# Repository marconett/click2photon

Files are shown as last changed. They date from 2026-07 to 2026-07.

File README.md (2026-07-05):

# click2photon

End-to-end display latency measurement: the time from a mouse click to a visible
change on screen, measured with a photodiode strapped to the monitor.

**How it works:**

- An RP2040 sends a USB HID mouse click
- The color switcher app toggles the screen black/white
- The photodiode picks up the change
- The RP2040 streams ADC samples over serial
- The host logs them to CSV
- `analyze.py` computes the latency

## Components

| Component | Path | Description |
|---|---|---|
| Hardware | `hardware/` | KiCad PCB, breadboard/perfboard layout, and 3D-printable enclosure for the sensor (BPW34 photodiode + TLC271IP transimpedance amplifier). |
| Firmware | `arduino/` | Runs on an Adafruit QT Py RP2040. Fires the mouse click, samples the photodiode (14-bit ADC, 12,000 samples per run), sends results as CSV lines over serial. Flash with `./flash_rp2040.sh`. |
| Host software | `main.py` | Interactive serial terminal. Starts/stops test runs, configures click count and interval, logs device data to `output/*.csv`. |
| Analyzer | `analyze.py` | Computes latency from a session CSV: delta-from-baseline threshold detection, reports per-click latency plus mean/sd/median/min/max. |
| Color switcher | `color-switcher-vulkan/` | C++ Vulkan app that toggles the screen black/white on click, built for minimal rendering latency. Build with `./build_vulkan.sh`, run with `./run_vulkan.sh`. |

## Images

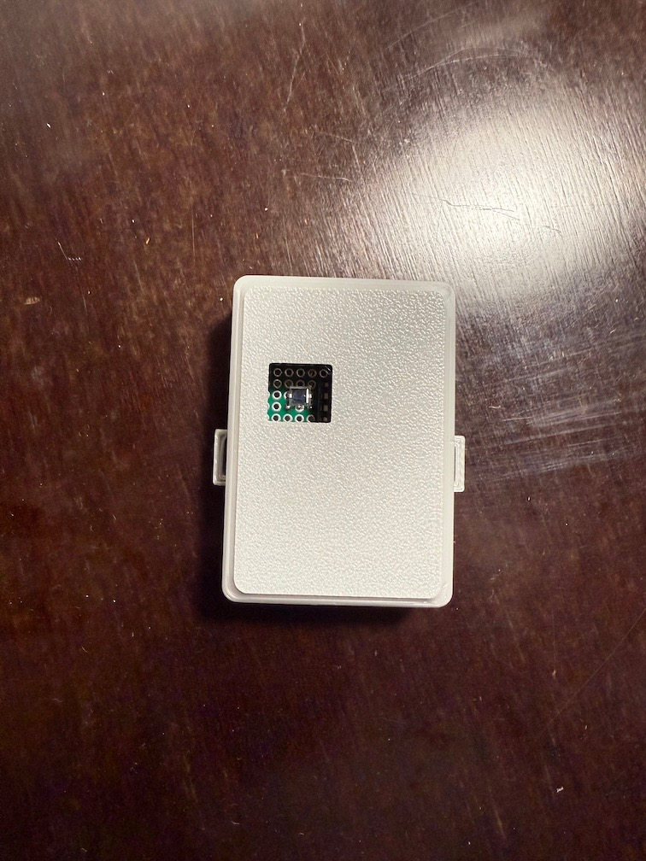
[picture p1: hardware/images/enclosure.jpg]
Enclosure
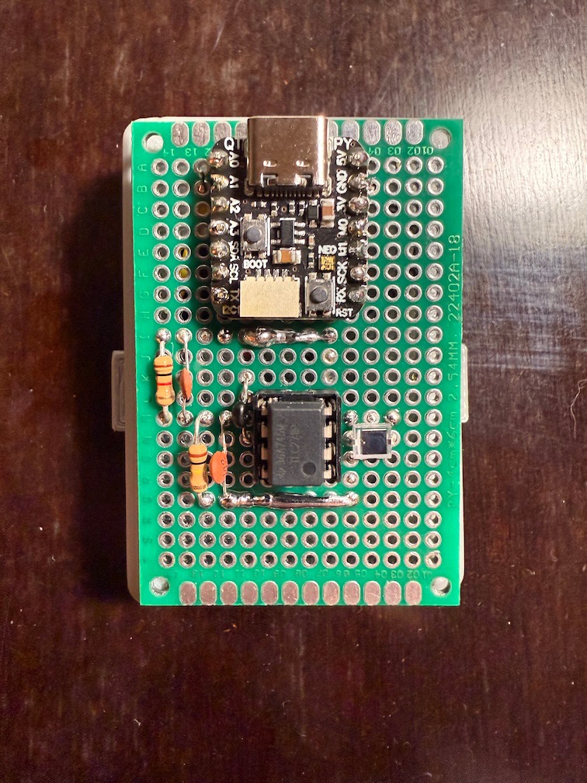
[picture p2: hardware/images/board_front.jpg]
Board
 

## Host software CLI (`main.py`)

Connects to the device on `/dev/cu.usbmodem101` at 115200 baud and provides an
interactive prompt:

| Command | Description |
|---|---|
| `start` | Start a test session (3s countdown). Logs to `output/<timestamp>_session.csv`. |
| `stop` | Stop the test and close the session CSV. |
| `debug`, `d` | Enable debug mode — device streams raw ADC readings and voltage. |
| `interval <float>`, `i <float>` | Set the time between clicks in seconds (default 0.5). |
| `clicks <int>`, `c <int>` | Set the number of clicks per session (default 10). |
| `connect` / `disconnect` | Open / close the serial connection. |
| `help` | Show the command list. |
| `exit`, `quit` | Disconnect and quit. |

## Usage

```sh
uv sync                     # set up Python environment
./run_vulkan.sh             # start the color switcher on the monitor under test
uv run main.py              # connect to the device, then type: start
uv run analyze.py output/<session>.csv
```

## Similar tools

Multiple similar (and likely better) tools / devices exist:

- [m2p-latency](https://github.com/davidramiro/m2p-latency)
- [Open-Source-LDAT](https://github.com/S4N-T0S/Open-Source-LDAT)
- [OSLTT](https://github.com/OSRTT/OSLTT)

As well as amazing articles detailing the process and results:

- By @farnoy: [Linux latency measurements and compositor tuning](https://farnoy.dev/posts/linux-latency)
- By @davidramiro: [Building an Input Latency Meter (Because ‘Wayland Feels Off’ Isn’t a Metric)](https://davidjusto.com/articles/m2p-latency/)

For fun, I let Claude Fable 5 compare the 4 projects: [COMPARISON.md](./COMPARISON.md).

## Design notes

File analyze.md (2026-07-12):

# analyze.py output explained

Each value describes the click-to-photon latencies of one file or one pooled folder (all clicks from all its CSV files together).

- **measurements** — number of clicks with a detected screen change. *skipped* = clicks where no change crossed the threshold (bad sample, missed click); they are excluded from all stats.

- **mean ± … (95% CI)** — average latency. The ± is the uncertainty of that average: rerunning the same test would land the mean inside this range 95% of the time. Two cases whose ranges don't overlap are genuinely different. For folders, the margin is widened if the individual sessions disagree with each other.

- **median** — the middle click: half were faster, half slower. Like the mean but immune to a few extreme values.

- **p5** — the fast tail: 5% of clicks were faster than this. Approximates the best-case pipeline latency (click landed at the luckiest moment of the refresh cycle). A robust version of *min*.

- **p95** — the slow tail: 5% of clicks were slower than this. The "feels laggy" number — worst cases players actually notice. Where frame-pacing features should show their effect.

- **spread (p95 − p5)** — consistency: how wide the typical latency range is. Smaller = more predictable feel. More meaningful than sd, which is inflated the same way everywhere.

- **min / max** — single fastest and slowest click. Sanity checks only; each is one sample, so don't base conclusions on them.

- **histogram** — latency distribution in 0.5 ms bins; each row shows a bin's count as a bar. Shows the shape a single number can't: whether the whole block shifts between cases, whether a case has a longer tail, or whether clicks clump at multiples of the 2 ms frame period.

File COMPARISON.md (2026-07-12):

# Comparing four open-source display latency testers

A comparison of this project (**click2photon**) against three tools that fulfil the same purpose:

- [davidramiro/m2p-latency](https://github.com/davidramiro/m2p-latency)
- [S4N-T0S/Open-Source-LDAT](https://github.com/S4N-T0S/Open-Source-LDAT)
- [OSRTT/OSLTT](https://github.com/OSRTT/OSLTT)

**Quick orientation:** all four measure "input event → visible photon" with a light sensor on the screen, but they split into two design philosophies. **m2p-latency** and **Open-Source-LDAT** are *standalone devices*: they time a live threshold crossing on the microcontroller and show summary stats on an OLED — no host software, no raw data. **OSLTT** and **click2photon** are *capture-and-analyze systems*: the firmware records a full ADC waveform per shot and streams it to the PC, where detection happens offline. This project is visibly a hybrid of the other three — it shares OSLTT's capture architecture almost exactly (14-bit ADC, 12,000 samples, 115200 baud, near-identical CSV header), m2p's delta-from-baseline detection algorithm (credited in `analyze.py`), and OSLTT's dedicated black/white test app idea (the Vulkan color-switcher vs. their DirectX window).

## 1. Measurement approach

| | m2p-latency | Open-Source-LDAT | OSLTT | click2photon |
|---|---|---|---|---|
| Input event | Mouse **move** (±127 px) via ATmega32U4 HID | Real-mouse switch injection (transistor) **or** Teensy as 8 kHz HID mouse | HID keyboard space / mouse click / mouse move | `Mouse.press()` via RP2040 HID |
| Detection | Live busy-poll, \|delta from 1-sample baseline\| > 20 (10-bit) | Live busy-poll, fixed threshold w/ hysteresis (>15 / <10 on 8-bit) | Waveform capture → host-side smoothing + slope-confirmation lookaheads | Waveform capture → host-side \|delta from 200-sample baseline\| > 100 (14-bit) |
| Timing location | On MCU (`micros()`) | On MCU (`elapsedMicros`) | MCU captures, host detects | MCU captures, host detects |
| Raw data kept | No | No (only per-run ms to SD, optionally) | Yes (full 12k-sample CSV) | Yes (full 12k-sample CSV) |
| Pre-click baseline | 1 sample | None (fixed thresholds) | None — capture starts *at* the click; baseline inferred from first 50 samples | 2,000 samples (~48 ms) before the click |

The most important architectural differences:

- **What the click includes.** Open-Source-LDAT's "Automatic" mode is unique: it electrically actuates a *real mouse's* switch, so the measurement includes the mouse's own hardware/firmware/debounce latency — true click-to-photon, and anticheat-invisible (the device can run PC-disconnected on a power bank). Everyone else emulates a HID device, which measures system+display latency but excludes real-mouse internals.
- **Pre-click history.** This project is the only one that samples *before* the click (2,000 samples), giving a proper averaged baseline and letting you see ADC drift. OSLTT starts capturing after the HID call returns and adds the call duration back arithmetically; m2p uses one un-averaged sample as baseline; LDAT uses no baseline at all, just fixed thresholds that must be hand-tuned per monitor.
- **Detection sophistication.** OSLTT has the most elaborate detector (10-sample moving average, pulse/rising/falling branches, multi-point lookahead confirmation at +50/+100/+150 samples, adaptive false-trigger handling) — robust but complex. This project's and m2p's simple delta-threshold is easier to reason about but sensitive to threshold choice; LDAT's fixed absolute threshold is the crudest but runs at the highest speed.

## 2. Measurement accuracy

| | m2p-latency | Open-Source-LDAT | OSLTT | click2photon |
|---|---|---|---|---|
| ADC resolution | 10-bit (overclocked, noisy) | 8-bit (deliberately, for speed) | 14-bit | 14-bit |
| Effective sample interval | ~13–20 µs | ~1–3 µs (600 MHz busy-poll) | ~15.27 µs | ~24 µs (20 µs settling + read) |
| Timer resolution | 4 µs | 1 µs | 1 µs | 1 µs |
| Refresh-phase decorrelation | 574 ms delay (non-divisor of refresh) | Entropy-seeded ±10 ms random jitter | Configurable 0.5–8 s delay, no jitter | Fixed interval, no jitter |
| Stats | Mean + sample SD over 20 runs | Running mean/min/max, B→W and W→B tracked separately | Mean/min/max + **median-based outlier rejection** (>3× or <⅓ median dropped) | Mean, sample SD, median, min/max |
| Calibration aids | Live sensor bar for positioning; fixed 40 µs internal-latency subtraction | Boot-time sensor stability self-check; debug live-ADC mode; thresholds need reflash to change | Per-run sample-period self-calibration; frame-time subtraction | Documented 20 µs settling fix; `-t` threshold override |

Accuracy verdicts per tool:

- **Open-Source-LDAT** has the best *temporal* precision (sub-3 µs detection granularity, 1 µs timer, genuine 8 kHz USB polling via a build-time Teensy core patch that cuts HID poll quantization to 0–125 µs) but the worst *amplitude* precision (8-bit ADC, fixed thresholds calibrated for OLED monitors — LCD users must retune). Its README is also the most honest about the latency pipeline: min/max spread of several ms is expected physics (frame timing + scanout), not instrument error.
- **OSLTT** is the only one that decomposes the result: it measures the test window's frame time (~1000 FPS DirectX app, QueryPerformanceCounter) and reports `onDisplayLatency = total − frameTime`, plus a "pretest" mode that subtracts system baseline to isolate game-engine latency. It's also the only one with outlier rejection. Weaknesses admitted in its own code: frame time is logged one frame late, and the moving average shifts the detected transition by 10 samples.
- **m2p-latency** is the roughest: single-sample baseline, ADC clocked 8× beyond its datasheet accuracy limit, 4 µs timer, USB poll jitter of the Pro Micro uncharacterized. The README itself calls it "a rough estimate." Its one clever accuracy feature — the 574 ms inter-cycle delay chosen not to divide the refresh rate — reappears in stronger form as LDAT's randomized jitter.
- **click2photon** has the best amplitude fidelity of the capture-based pair: 14-bit ADC *plus* the 20 µs settling delay (OSLTT reads flat-out with no settling, which compresses dynamic range), and the only real pre-click baseline. Trade-offs: the ~24 µs sample interval quantizes detection slightly coarser than OSLTT's ~15 µs, latency is reconstructed as `index × (timeTaken/sampleCount)` (assumes uniform sample spacing), and there is no refresh-phase jitter/decorrelation between shots — worth stealing from LDAT.

## 3. Hardware choice

| | m2p-latency | Open-Source-LDAT | OSLTT | click2photon |
|---|---|---|---|---|
| MCU | Arduino Pro Micro (ATmega32U4, 16 MHz, ~$8) | Teensy 4.1 (Cortex-M7 @ 600 MHz, ~$35) | Seeeduino XIAO / custom SAMD21 PCB | Adafruit QT Py RP2040 (~$10) |
| Sensor | TEMT6000 phototransistor breakout | TEMT6000 phototransistor breakout | VBPW34SR photodiode + TSV7721 transimpedance amp (1 MΩ) | BPW34 photodiode + TLC271 transimpedance amp |
| Extra hardware | SSD1306 OLED, MX button | SSD1306 OLED, button, BC547 mouse-injection circuit, microSD logging | Mic input + amp, 2-pin/3-pin trigger inputs, button, LED; sold as assembled kit | KiCad PCB, breadboard layout, 3D-printed enclosure |
| Approx. cost | ~$15–20 | ~$45–55 + donor mouse | Commercial kit (osrtt.com); ~$10–20 BOM class | ~$15–25 |

Two meaningful splits here. First, **phototransistor vs. photodiode+amp**: the TEMT6000 (m2p, LDAT) is a $2 plug-and-play breakout — simple but slower and less linear. This project and OSLTT independently chose the harder path of a PIN photodiode with a transimpedance amplifier, which gives faster, more linear response at the cost of analog design work (BPW34+TLC271 vs. their VBPW34SR+TSV7721 are essentially the same circuit with different parts). Second, **MCU horsepower**: LDAT's Teensy 4.1 is wildly overpowered on purpose — the 600 MHz core is what buys the ~1 µs detection loop. The other three all use ~$5–10 hobby boards where USB HID support was the actual selection criterion. OSLTT is the only one that graduated to a custom manufactured PCB sold as a product.

## 4. Ease of use

- **m2p-latency** is the easiest to *operate*: plug in USB, point at testufo.com/flicker or a game, press the button, read mean±σ off the OLED 20 clicks later. No software, OS-agnostic. But it's the least flexible — changing anything (cycle count, threshold) means recompiling, and there's no data export at all.
- **Open-Source-LDAT** is the hardest to *build* (soldering, sacrificing a mouse for Automatic mode, per-monitor threshold tuning that requires editing `config.h` and reflashing via PlatformIO) but pleasant to run: one-button on-device menu, run limits of 10/100/300/500/unlimited, live stats, optional CSV to microSD. It needs a third-party "latency marker" on screen (NVIDIA Reflex flash indicator, RTSS FCAT bar, or Aperture Grille) — those tools are Windows-centric even though the device itself is OS-agnostic. Documentation is excellent.
- **OSLTT** is the most polished end-user experience by far — it's a commercial product: Windows installer, GUI that auto-installs drivers and auto-flashes firmware updates, built-in ~1000 FPS DirectX test window, up to 990 automated shots, result charts, CSV export of both raw and processed data, and extra modes nobody else has (peripheral click latency via microphone/electrical tap, audio latency, controller latency). The cost: Windows-only, closed ecosystem feel, and a large codebase its own author calls imperfect.
- **click2photon** is the most developer/researcher-oriented: CLI workflow (`uv run main.py`, `uv run analyze.py`), full raw waveforms in versioned CSVs, a purpose-built low-latency Vulkan test app, and macOS support — which none of the other three targets (OSLTT is Windows-only; the standalone devices are OS-agnostic but their recommended marker apps are Windows tools). The trade-off is that it's a three-part manual workflow (start Vulkan app, run terminal UI, run analyzer) with no GUI and no on-device operation.

## Takeaways

Ideas worth borrowing: **LDAT's randomized inter-shot jitter** (decorrelating from display refresh) is a cheap accuracy win the fixed-interval firmware currently lacks, and **LDAT's real-mouse switch injection** is the only approach here that captures true click-to-photon including mouse hardware latency. Conversely, the combination of pre-click baseline sampling, 14-bit ADC with settling delay, and full waveform retention gives this project better post-hoc analyzability than any of the three references — none of them can re-analyze old runs with a different detection algorithm, and this one can.

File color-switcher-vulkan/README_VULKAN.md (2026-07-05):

# Vulkan Color Switcher

### Installation on macOS

```bash
brew install vulkan-headers vulkan-loader molten-vk glfw cmake
```

## Building

```bash
cd color-switcher-vulkan/build
cmake ..
cmake --build .
```

## Running

```bash
./color-switcher-vulkan/build/bin/color-switcher-vulkan
```

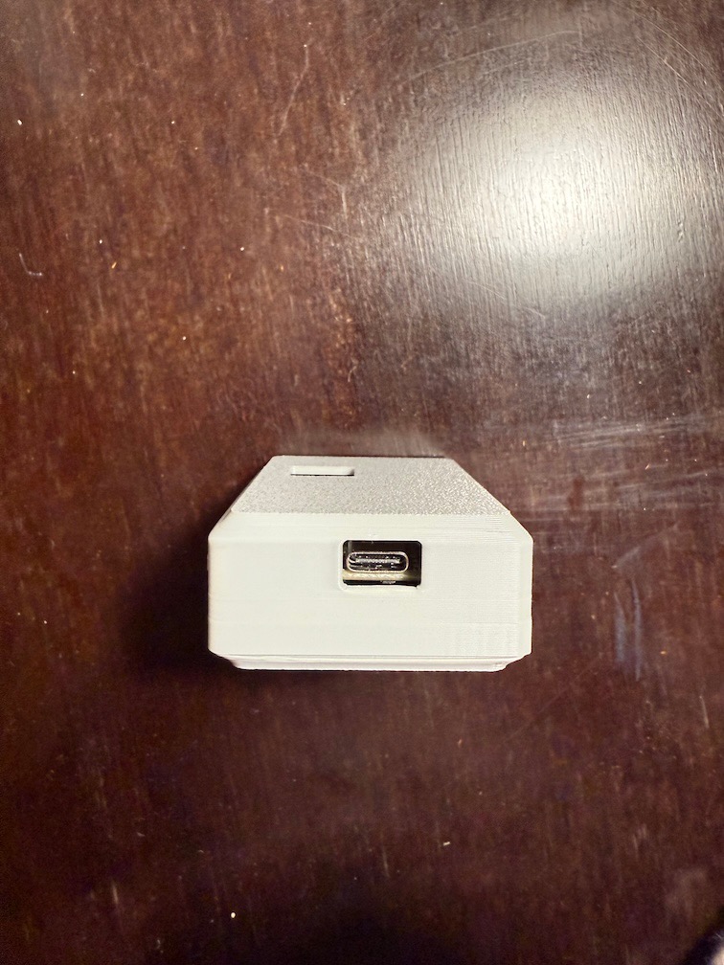
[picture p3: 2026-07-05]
hardware/images/enclosure_side.jpg

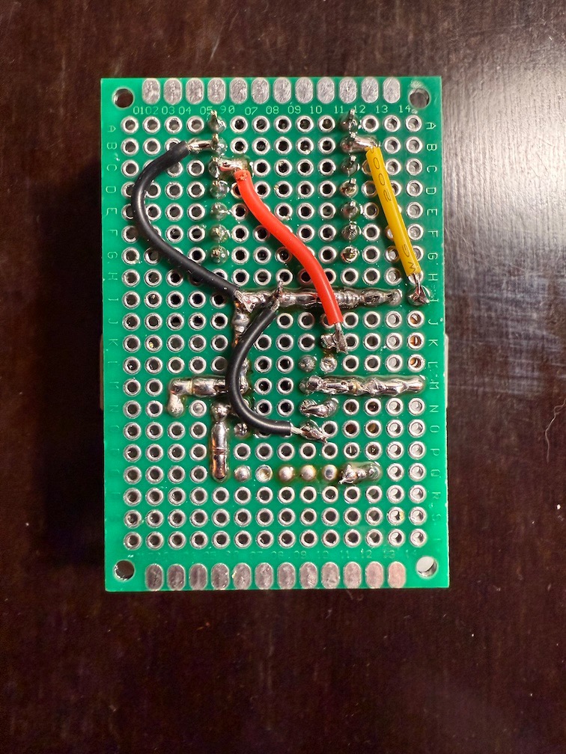
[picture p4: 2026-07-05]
hardware/images/board_back.jpg

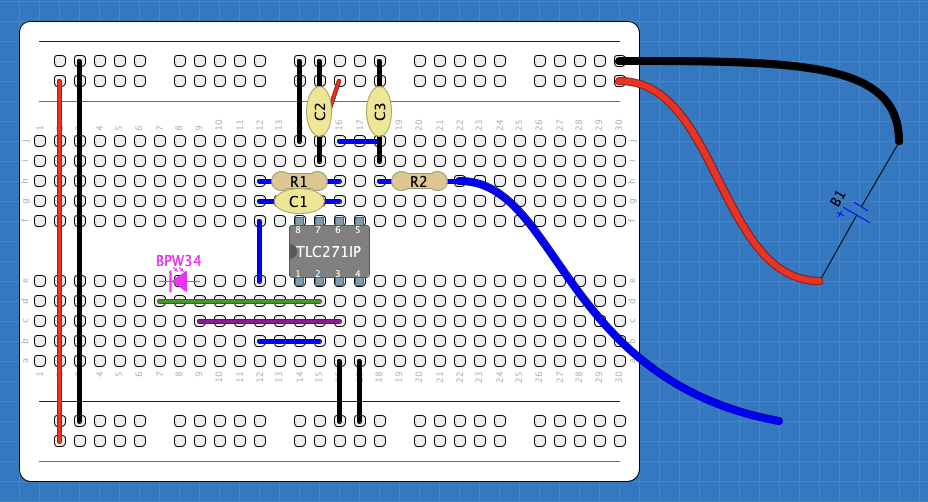
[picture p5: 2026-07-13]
hardware/breadboard.png

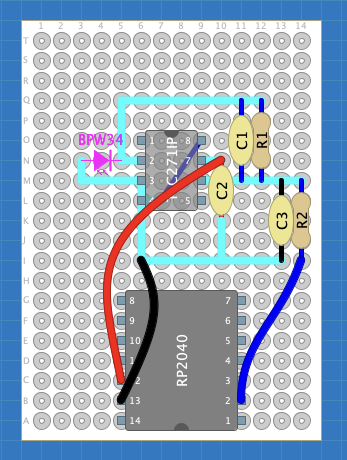
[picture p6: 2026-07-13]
hardware/perfboard.png

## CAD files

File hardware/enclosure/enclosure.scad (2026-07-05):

include <./YAPPgenerator_v3.scad>

pcbLength = 40;
pcbWidth = 60;
pcbThickness = 1.6;

// paddingFront = 1.5;
// paddingBack = 1.5;
// paddingRight = 2.5;
// paddingLeft = 2.5;

// ridgeHeight = 6;
lidWallHeight  = 13;
baseWallHeight = 6;
wallThickness = 2;

standoffHeight = 6;
standoffDiameter = 4.5;
standoffPinDiameter = 1.94;
standoffHoleSlack = 0.6;

// * Print settings *
// printLidShell = false;
// printBaseShell = false;

// * Debug settings *
// showPCB = true;
// hideLidWalls = true;
// showSideBySide = false;
// onLidGap = 6;

// snapJoins = [
//     [6, 6, yappLeft, yappRight],
//     [pcbLength+paddingRight+paddingLeft-6, 6, yappLeft, yappRight]
// ];

pcbStands = [
    [2.5, 2.5, standoffHeight, yappDefault, standoffDiameter, standoffPinDiameter, standoffHoleSlack, 0, yappBoth, yappPin, yappAllCorners, yappCoordPCB]
];

// hole for usb-c connector
cutoutsLeft = [
    [
      ((pcbLength-13)/2) + 2.54, // from Back
      3, // from Left
      11, // width
      7, // length
      1, // radius
      yappRoundedRect, // shape
      0, // depth
      0, // angle
      // yappCenter,
      yappCoordPCB,
    ]
];

// hole for the photodiode
cutoutsLid = [
    [5, 33, 13, 12, 6, yappRectangle]
];

// module hookLidInside()
// {
  // translate([20, 34, -5])
  //   cube([2, 12, 12]);

  // translate([20+14, 34, -5])
  //   cube([2, 12, 12]);

  // translate([20, 34-2, -5])
  //   cube([16, 2, 12]);

  // translate([20, 34+12, -5])
  //   cube([16, 2, 12]);
// }

// guides for the elastic band
module hookLidOutside()
{
  // back
  // base x value: -4
  translate([-6, 20, -12.5])
    cube([2, 10, 3]);

  translate([-6, 20, -12.5])
    cube([4, 2, 3]);

  translate([-6, 30, -12.5])
    cube([4, 2, 3]);

  // front
  // base x value: 44
  translate([46, 20, -12.5])
    cube([2, 10, 3]);

  translate([44, 20, -12.5])
    cube([4, 2, 3]);

  translate([44, 30, -12.5])
    cube([4, 2, 3]);
}

YAPPgenerate();

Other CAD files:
hardware/enclosure/YAPPgenerator_v3.scad

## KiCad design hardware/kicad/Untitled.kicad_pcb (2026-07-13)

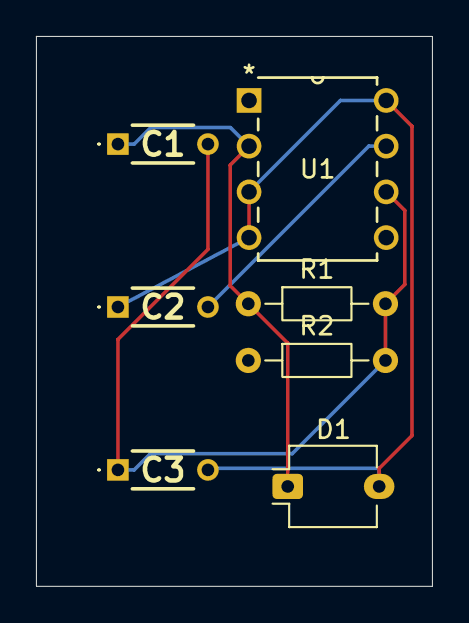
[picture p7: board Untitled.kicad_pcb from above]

Board: 2 copper layers, 22.0 x 30.5 mm, 7 parts (0 on the bottom side), 4 nets.

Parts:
C1: 1pF; K104K15X7RF53H5G
C2, C3: 100nF; K104K15X7RF53H5G
D1: BPW34; Osram_DIL2_4.3x4.65mm_P5.08mm
R1: 100kΩ; R_Axial_DIN0204_L3.6mm_D1.6mm_P7.62mm_Horizontal
R2: 1kΩ; R_Axial_DIN0204_L3.6mm_D1.6mm_P7.62mm_Horizontal
U1: TLC271IP

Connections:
+3.3V: C2.2, U1.7 (VDD)
GND: C2.1, C3.2, D1.2 (A), U1.3 (IN+), U1.4 (GND), U1.8 (BIASSELECT)
unnamed: C1.1, D1.1 (K), R1.1, U1.2 (IN-)
unnamed: C1.2, C3.1, R1.2, R2.2, U1.6 (OUT)

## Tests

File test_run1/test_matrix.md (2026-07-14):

# Test Matrix

Three dimensions, two values each → **8 test cases**.

**Dimensions**
- **Display server:** X11 / Wayland
- **`PROTON_DXVK_LOWLATENCY`:** ON / OFF
- **VRR:** ON / OFF

- Plus another 2 special test cases for XWayland
- Plus another 2 special test cases for low-latency

---

## Test Cases

| #  | Display | LOWLATENCY | VRR | Special case | Done |
|----|---|---|-----|---|---|
| 1  | X11 | ON | ON  | - | [x]  |
| 2  | X11 | ON | OFF | - | [x]  |
| 3  | X11 | OFF | ON  | - | [x]  |
| 4  | X11 | OFF | OFF | - | [x]  |
| 5  | Wayland | ON | ON  | - | [x]  |
| 6  | Wayland | ON | OFF | - | [x]  |
| 7  | Wayland | OFF | ON  | - | [x]  |
| 8  | Wayland | OFF | OFF | - | [x]  |
| 9  | Wayland | ON | OFF | XWayland | [x]  |
| 10 | Wayland | OFF | OFF | XWayland | [x]  |
| 11 | X11 | ON | OFF | Uncapped | [x]  |
| 12 | X11 | OFF | OFF | Uncapped | [x]  |

---

## Per-Case Notes

### Case 1 — X11 · LOWLATENCY ON · VRR ON
- stable 480 fps

```conf
# dxvk.conf
dxgi.maxFrameRate = 480
dxvk.lowLatencyOffset = 70
dxvk.framePace = "low-latency-vrr-500"
dxvk.lowLatencyAllowCpuFramesOverlap = False
```

### Case 2 — X11 · LOWLATENCY ON · VRR OFF
- stable 500 fps

```conf
# dxvk.conf
dxgi.maxFrameRate = 500
```

### Case 3 — X11 · LOWLATENCY OFF · VRR ON
- stable 497 fps

```conf
# dxvk.conf
dxgi.maxFrameRate = 497
```

### Case 4 — X11 · LOWLATENCY OFF · VRR OFF
- stable 500 fps

```conf
# dxvk.conf
dxgi.maxFrameRate = 500
```

### Case 5 — Wayland · LOWLATENCY ON · VRR ON
- stable 480 fps

```conf
# dxvk.conf
dxgi.maxFrameRate = 480
dxvk.lowLatencyOffset = 70
dxvk.framePace = "low-latency-vrr-500"
dxvk.lowLatencyAllowCpuFramesOverlap = False
```

### Case 6 — Wayland · LOWLATENCY ON · VRR OFF
- stable 500 fps

```conf
# dxvk.conf
dxgi.maxFrameRate = 500
```

### Case 7 — Wayland · LOWLATENCY OFF · VRR ON
- stable 497 fps

```conf
# dxvk.conf
dxgi.maxFrameRate = 497
```

### Case 8 — Wayland · LOWLATENCY OFF · VRR OFF
- stable 500 fps

```conf
# dxvk.conf
dxgi.maxFrameRate = 500
```

### Case 9 — Wayland · LOWLATENCY ON · VRR OFF · XWayland
- special case: comparing XWayland vs native wayland
- stable 500 fps

```conf
# dxvk.conf
dxgi.maxFrameRate = 500
```

### Case 10 — Wayland · LOWLATENCY OFF · VRR OFF · XWayland
- special case: comparing XWayland vs native wayland
- stable 500 fps

```conf
# dxvk.conf
dxgi.maxFrameRate = 500
```

### Case 11 — X11 · LOWLATENCY ON · VRR OFF · uncapped
- special case: comparing low-latency on vs off
- ~670 fps (95-97% gpu usage - intentional, that's what the low-latency pacer does)

```conf
# dxvk.conf
```

### Case 12 — X11 · LOWLATENCY OFF · VRR OFF · uncapped
- special case: comparing low-latency on vs off
- ~715 fps (100% usage gpu-bound)

```conf
# dxvk.conf
```

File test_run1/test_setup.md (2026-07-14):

# Test setup

## Hardware

- Mainboard: B450 GAMING PRO CARBON AC
- CPU: AMD Ryzen 7 5800X3D (16) @ 4.55 GHz
- GPU: NVIDIA GeForce RTX 4070 SUPER
- RAM: 2x8GB DDR4, 3200 MHz
- Monitor: MSI MAG 272QP QD-OLED X50 (500 Hz)
- Only one screen was connected to the system during the test

## Software

```sh
{
    echo "date: $(date -I)"
    echo "kernel: $(uname -r)"
    pacman -Q kwin
    pacman -Q xorg-server
    pacman -Q nvidia-utils
    pacman -Q proton-cachyos
    scxctl get
  } | tee versions.txt
```

Output:

```
date: 2026-07-12
kernel: 7.1.3-2-cachyos
kwin 6.7.2-1.1
xorg-server 21.1.24-1.1
nvidia-utils 610.43.03-1
proton-cachyos-native 1:11.0.20260602-3
no scx scheduler running
```

The test was done based on commit `7bc3f05` of click2photon.

## System Settings

- 500 Hz
- Flip mode:
  - X11: On (via `nvidia-settings`)
  - Wayland: confirmed to be on (see below how)
- If VRR was tested:
  - X11: Enabled via `nvidia-settings` (changing this requires a reboot)
  - Wayland: Enabled via KDE Settings Menu (no reboot needed)
- `showcompositing` was off on Wayland (see [here](https://www.reddit.com/r/linux_gaming/comments/1u1z4qf/kde_kwin_patches_aiming_to_optimize_gaming/oqvlwdb/))

Flip mode (direct scanout) vs Blit mode (compositing) on Wayland: There is setting on Wayland, it decides itself if it composits a frame or uses direct scanout.\
To make sure the game is running in flip mode: Open "Kwin Debug Console" (it's a GUI tool) and in the "Effects" tab, enable `showcompositing`. Then make sure the game is fully focused and the only thing on screen in fullscreen mode. If there's no red border visible around the edged of the game, it's on Flip mode.

### dxvk

In all cases, the following is set in `dxvk.conf`:

```conf
d3d11.cachedDynamicResources = "c"
```

Depending on the test, an optimal `dxvk.conf` was setup:
- If VRR was off, `dxgi.maxFrameRate` was capped to 500 fps (the screens refresh rate)
- If VRR was on and `PROTON_DXVK_LOWLATENCY` was off, `dxgi.maxFrameRate` was capped to 497 fps (slightly below screen refresh rate)
- If VRR was on and `PROTON_DXVK_LOWLATENCY` was on, the following was used to utilize the low latency VRR frame pacing

```conf
# see https://github.com/netborg-afps/dxvk-low-latency
dxgi.maxFrameRate = 480
dxvk.lowLatencyOffset = 70
dxvk.framePace = "low-latency-vrr-500"
dxvk.lowLatencyAllowCpuFramesOverlap = False
```

## Game Settings

Test was done in Diabotical.

Settings:

- Everything Video Setting as low as possible
- 100% Render resolution
- Native resolution (2560×1440)
- Vsync off

## Methodology

- Close unnecessary Software
- Launch game
- Start a wipeout match, Map: wo_wellspring
- Move to a specific spot, put mouse on specific landmark
- Run the test case (100 clicks, runs for about 2 minutes)
- Once the test is done, start the next test case iteration

- Ingame conditions: No bots, no other players, no movement, no round restarts. It is basically just a static scene that will stay like this indefinitely.
- System conditions: During the test run, nothing else should be running and no significant other processes run on the system.

To start the test via click2photon:

```sh
uv run main.py
clicks 100
start
```

## Special test case: PROTON_ENABLE_WAYLAND

The setting "Enable wine-wayland" in Heroic Launcher corresponds to `PROTON_ENABLE_WAYLAND`. If not otherwise noted, all tests were done with `PROTON_ENABLE_WAYLAND=1` (native Wayland, no use of XWayland)

- `PROTON_ENABLE_WAYLAND=1` implies native Wayland
- `PROTON_ENABLE_WAYLAND=0` implies XWayland

## Setup notes

```sh
cd /home/hst/Games/Heroic/Diabotical/
cp diabotical.exe-TESTLATENCY diabotical.exe
```

In diabotical:
- `/bind mouse_left testlatency`
- Setup hud with accent box

```sh
cp diabotical.exe-ORIG diabotical.exe
```

Ingame: `/bind mouse_left attack`

## Ideas

Future test run ideas:

1. Testing different kernel schedulers:

```sh
sudo scxctl start --sched cosmos --mode gaming
sudo scxctl start --sched lavd --mode gaming
sudo scxctl stop
```

2. Compare against: https://themaister.net/blog/2026/07/02/my-side-quest-measuring-input-latency-with-vk_ext_present_timing/

3. Try different compositors (niri)

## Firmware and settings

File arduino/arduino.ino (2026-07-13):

#include <Mouse.h>
#include <Adafruit_NeoPixel.h>

#define NUMPIXELS 1

Adafruit_NeoPixel pixelLED(NUMPIXELS, PIN_NEOPIXEL, NEO_GRB + NEO_KHZ800);

// override arduino-pico's weak default of 10 (USB.cpp) — a 10ms HID bInterval
// adds a uniform 0-10ms host-poll delay to every measurement; 1ms matches a
// 1000Hz gaming mouse
int usb_hid_poll_interval = 1;

void setup() {
  // init serial
  Serial.begin(115200);
  while(!Serial); // wait for device to come online
  delay(2000); // Give time for USB to stabilize

  // init neopixel
  pinMode(NEOPIXEL_POWER, OUTPUT);
  digitalWrite(NEOPIXEL_POWER, HIGH);

  pixelLED.begin();
  pixelLED.setBrightness(20);
  pixelLED.setPixelColor(0, pixelLED.Color(255, 0, 0));
  pixelLED.show();

  analogReadResolution(14); // set ADC resolution to 14 bits (0-16383)

  // seed RNG from ADC noise — unseeded random() repeats the same sequence every
  // boot, which would make the inter-click jitter identical across sessions
  uint32_t seed = micros();
  for (int i = 0; i < 32; i++) {
    seed = (seed << 1) ^ analogRead(A1);
  }
  randomSeed(seed);

  // init mouse
  Mouse.begin();
}

bool isRunning = false;
bool isDebugRunning = false;
float timeBetweenClicks = 0.5; // seconds
int clickCount = 10;
int currentClickCount = 0;

#define SampleCount 12000
#define PreClickSamples 2000 // ~48ms of baseline before click, enough for ADC drift to settle (~12ms)
uint16_t adcBuff[SampleCount];

void runTest() {
    int currentSampleCount = 0;
    unsigned long startTimer = micros();

    // Phase 1: collect pre-click baseline samples (ADC drift settles within ~12ms)
    while (currentSampleCount < PreClickSamples) {
      adcBuff[currentSampleCount] = analogRead(A1);
      currentSampleCount++;
      delayMicroseconds(20);
    }

    // Phase 2: fire the click
    unsigned long clickTime = micros();
    Mouse.press(MOUSE_LEFT);
    unsigned long afterClick = micros();
    unsigned long clickDuration = afterClick - clickTime;

    // Phase 3: collect post-click samples capturing the transition
    while (currentSampleCount < SampleCount) {
      adcBuff[currentSampleCount] = analogRead(A1);
      currentSampleCount++;
      delayMicroseconds(20);
    }

    unsigned long endTimer = micros();
    unsigned long timeTaken = endTimer - startTimer;

    Mouse.release(MOUSE_LEFT);

    Serial.print("CSV");
    Serial.print(clickDuration);
    Serial.print(",");
    Serial.print(timeTaken);
    Serial.print(",");
    Serial.print(SampleCount);
    Serial.print(",");
    Serial.print(PreClickSamples); // click sample index so host knows where the click happened
    Serial.print(",");

    for (int i = 0; i < SampleCount; i++) {
      Serial.print(adcBuff[i]);
      Serial.print(";");
    }

    Serial.println();
    Serial.flush(); // wait for serial data to fully transmit before next measurement — HID and CDC share the USB bus, so lingering serial traffic can delay Mouse.press() delivery
}

void loop() {
  /*
   * Serial toggle
  */
  if (Serial.available()) {
    char cmd = Serial.read();

    if (cmd == '1') {
      pixelLED.setBrightness(0);
      pixelLED.show();

      Serial.println("Starting latency test in 3 seconds...");
      Serial.println("Current time between clicks: " + String(timeBetweenClicks) + " seconds");
      Serial.println("Current click count: " + String(clickCount));

      delay(3000);
      isRunning = true;
    } else if (cmd == '0') {
      isRunning = false;
      isDebugRunning = false;
      currentClickCount = 0;

      Serial.println("Stopped");
      pixelLED.setBrightness(20);
      pixelLED.setPixelColor(0, pixelLED.Color(255, 0, 0));
      pixelLED.show();
    } else if (cmd == 'd') {
      pixelLED.setBrightness(0);
      pixelLED.show();

      Serial.println("Enabled debug mode");
      isDebugRunning = true;
    } else if (cmd == 'i') {
      float newInterval = Serial.parseFloat();
      if (newInterval > 0) {
        timeBetweenClicks = newInterval;
        Serial.println("Interval set to: " + String(timeBetweenClicks) + " seconds");
      } else {
        Serial.println("Invalid interval value");
      }
    } else if (cmd == 'c') {
      long newClickCount = Serial.parseInt();
      if (newClickCount > 0) {
        clickCount = newClickCount;
        Serial.println("click count set to: " + String(clickCount));
      } else {
        Serial.println("Invalid click count value");
      }
    }
  }

  // unsigned long PERF_start = micros();
  // unsigned long PERF_stop = micros();
  // Serial.print("PERF,");
  // Serial.println(PERF_stop - PERF_start);

  if (isRunning) {
    if (currentClickCount < clickCount) {
      // Serial.println("Click " + String(currentClickCount+1) + " of " + String(clickCount));
      runTest();

      // ±10ms random jitter decorrelates click timing from the display refresh
      // phase — a fixed interval can repeatedly land at the same scanout
      // position. Generated in µs, not ms: whole-ms offsets modulo a 2ms frame
      // period (500Hz) hit only two phases; µs resolution covers all of them.
      long delayUs = (long)(timeBetweenClicks * 1000000.0f) + random(-10000, 10001);
      if (delayUs < 0) delayUs = 0;
      delay(delayUs / 1000);
      delayMicroseconds(delayUs % 1000);
      currentClickCount++;
    } else {
      isRunning = false;
      currentClickCount = 0;
      pixelLED.setBrightness(20);
      pixelLED.setPixelColor(0, pixelLED.Color(255, 0, 0));
      pixelLED.show();

      Serial.println("DONE");
      Serial.flush();
      return;
    }
  }

  if (isDebugRunning) {
    uint16_t raw = analogRead(A1); // 14-bit ADC: 0 - 16383
    float voltage = (raw * 3.3) / 16383.0; // Convert to voltage
    Serial.print("Raw ADC: ");
    Serial.print(raw);
    Serial.print(", Voltage: ");
    Serial.println(voltage, 4);
  }
}

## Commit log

2026-07-12 auto-detect device / arduino auto setup
2026-07-12 analyze: only print summary
2026-07-12 Add +/-10ms microseconds-resolution random jitter to the inter-click delay so click timing can't alias with the display refresh phase
    [arduino.ino]
2026-07-13 fimware: 1000hz hid polling
2026-07-13 firmware: fixed minor bugs
    [arduino.ino]
2026-07-13 schematics: fix tlc wireing
    [Untitled.kicad_pcb, Untitled.kicad_sch]
